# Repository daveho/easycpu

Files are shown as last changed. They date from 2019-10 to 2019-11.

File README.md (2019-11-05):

# Easy 8 bit CPU

This is a design for an 8 bit CPU built from 74HC logic chips.

It is totally just for fun.  I may try to complete it at some point but for now it's only at the idea stage.

The [design](design) directory has a block diagram that is probably the most useful document for explaining how the CPU is intended to work.

One potentially useful component that is (probably) ready for use is a passive backplane design, which is in the [backplane2](backplane2) directory.

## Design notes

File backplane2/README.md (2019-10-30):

# Backplane

This is a passive backplane for projects (such as 8 bit micros and
TTL CPUs) where there are lots of parallel bus connections that
would be a pain to wire on breadboards.

The idea is that the project can be built incrementally, with
circuit modules prototyped on a small number of breadboards, and
then permanantly constructed and attached to the backplane.

The eventual finished system then uses the backplane to allow
the various circuit modules to communicate.

Kicad template from <https://github.com/Squantor/templates_kicad/tree/master/OSH_Park_2_layer>

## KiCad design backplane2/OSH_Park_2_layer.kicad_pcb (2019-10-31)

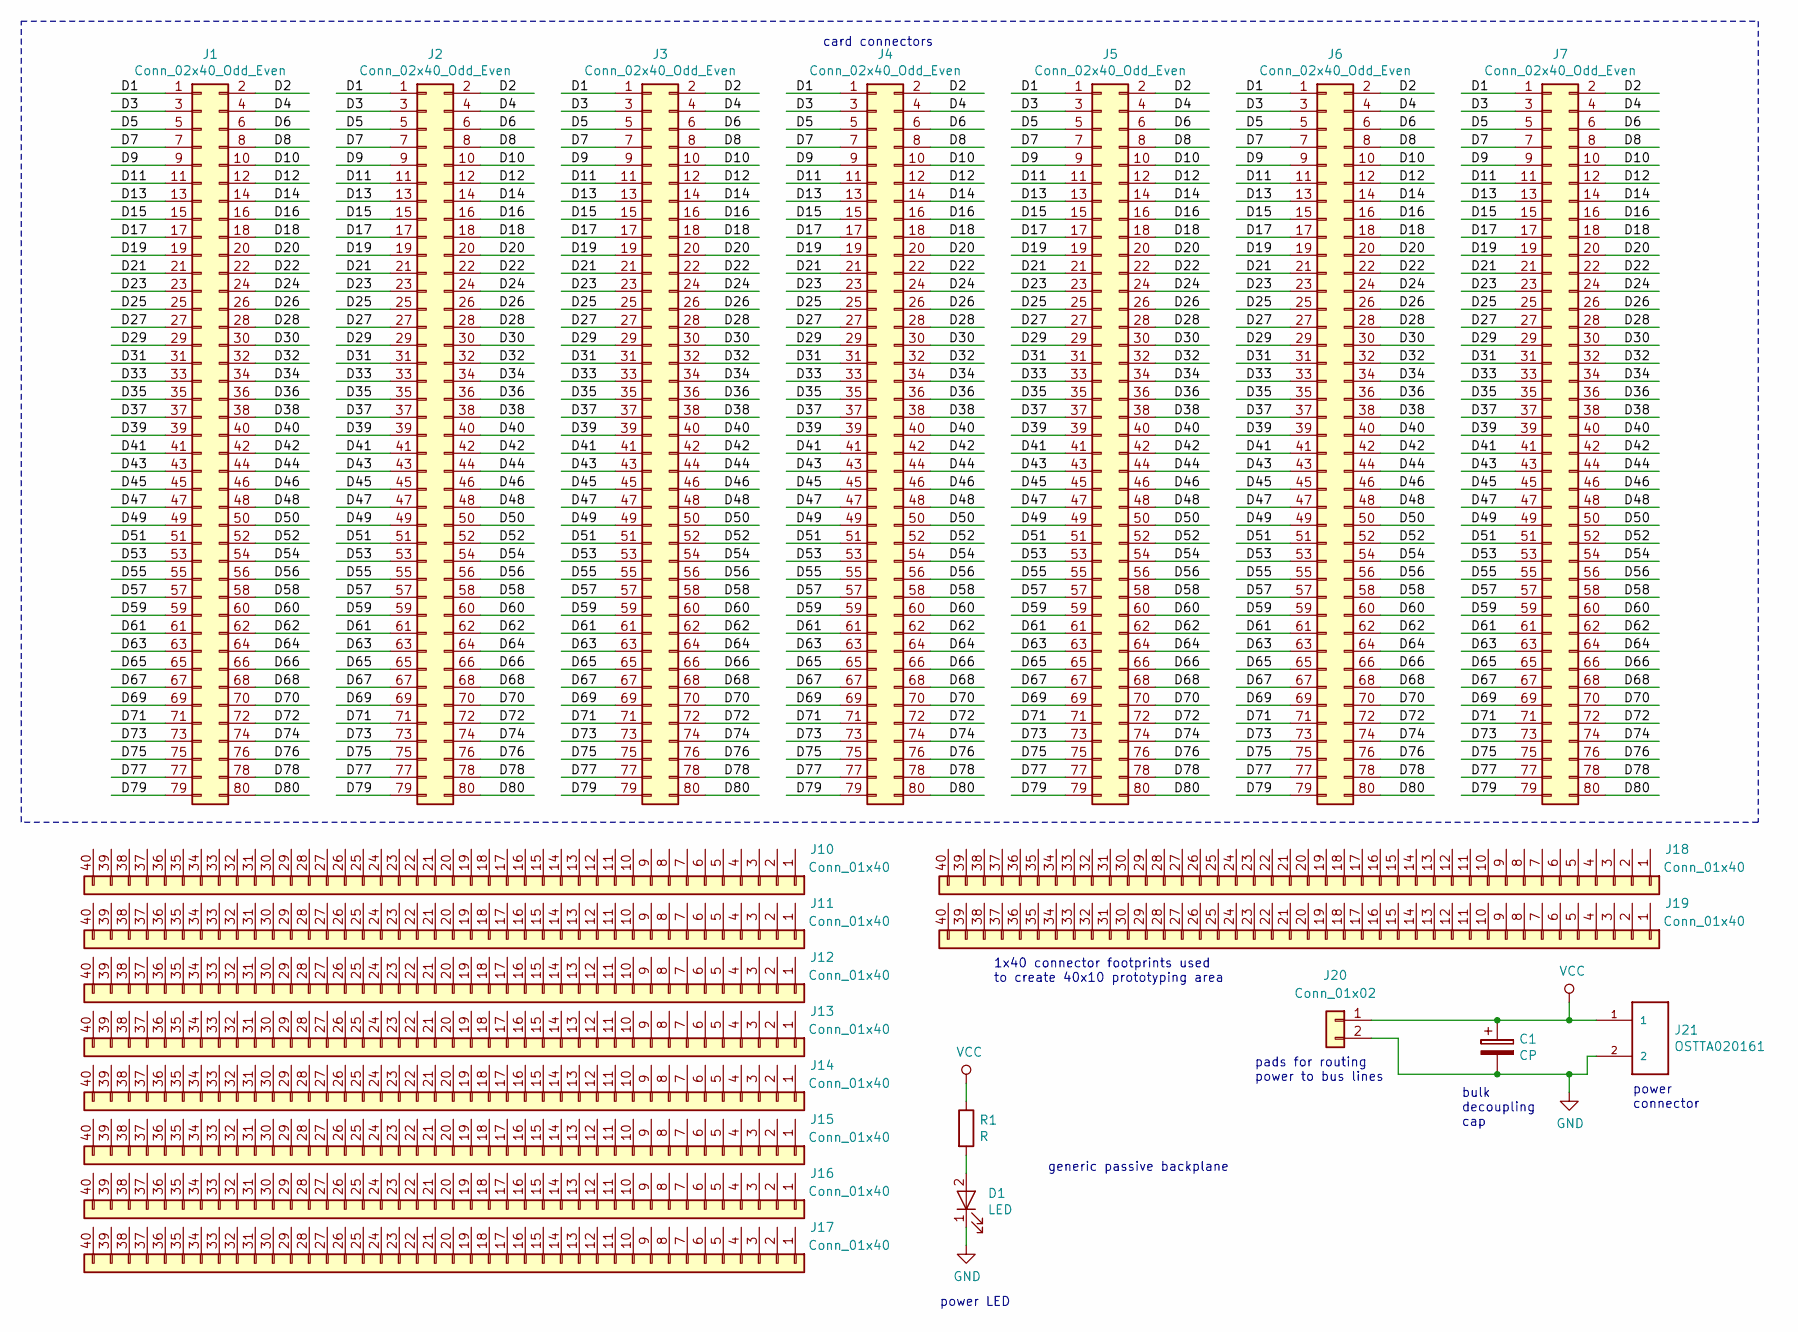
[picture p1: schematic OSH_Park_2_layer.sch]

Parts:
C1: CP; CP_Radial_D8.0mm_P2.50mm
D1: LED; LED_D5.0mm
J1, J2, J3, J4, J5, J6, J7: Conn_02x40_Odd_Even; PinHeader_2x40_P2.54mm_Vertical
J10, J11, J12, J13, J14, J15, J16, J17, J18, J19: Conn_01x40; PinHeader_1x40_P2.54mm_Vertical
J20: Conn_01x02; PinHeader_1x02_P2.54mm_Vertical
J21: OSTTA020161; OST_OSTTA020161
R1: R; R_Axial_DIN0204_L3.6mm_D1.6mm_P7.62mm_Horizontal

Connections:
/D1: J1.1, J2.1, J3.1, J4.1, J5.1, J6.1, J7.1
/D2: J1.2, J2.2, J3.2, J4.2, J5.2, J6.2, J7.2
/D3: J1.3, J2.3, J3.3, J4.3, J5.3, J6.3, J7.3
/D4: J1.4, J2.4, J3.4, J4.4, J5.4, J6.4, J7.4
/D5: J1.5, J2.5, J3.5, J4.5, J5.5, J6.5, J7.5
/D6: J1.6, J2.6, J3.6, J4.6, J5.6, J6.6, J7.6
/D7: J1.7, J2.7, J3.7, J4.7, J5.7, J6.7, J7.7
/D8: J1.8, J2.8, J3.8, J4.8, J5.8, J6.8, J7.8
/D9: J1.9, J2.9, J3.9, J4.9, J5.9, J6.9, J7.9
/D10: J1.10, J2.10, J3.10, J4.10, J5.10, J6.10, J7.10
/D11: J1.11, J2.11, J3.11, J4.11, J5.11, J6.11, J7.11
/D12: J1.12, J2.12, J3.12, J4.12, J5.12, J6.12, J7.12
/D13: J1.13, J2.13, J3.13, J4.13, J5.13, J6.13, J7.13
/D14: J1.14, J2.14, J3.14, J4.14, J5.14, J6.14, J7.14
/D15: J1.15, J2.15, J3.15, J4.15, J5.15, J6.15, J7.15
/D16: J1.16, J2.16, J3.16, J4.16, J5.16, J6.16, J7.16
/D17: J1.17, J2.17, J3.17, J4.17, J5.17, J6.17, J7.17
/D18: J1.18, J2.18, J3.18, J4.18, J5.18, J6.18, J7.18
/D19: J1.19, J2.19, J3.19, J4.19, J5.19, J6.19, J7.19
/D20: J1.20, J2.20, J3.20, J4.20, J5.20, J6.20, J7.20
/D21: J1.21, J2.21, J3.21, J4.21, J5.21, J6.21, J7.21
/D22: J1.22, J2.22, J3.22, J4.22, J5.22, J6.22, J7.22
/D23: J1.23, J2.23, J3.23, J4.23, J5.23, J6.23, J7.23
/D24: J1.24, J2.24, J3.24, J4.24, J5.24, J6.24, J7.24
/D25: J1.25, J2.25, J3.25, J4.25, J5.25, J6.25, J7.25
/D26: J1.26, J2.26, J3.26, J4.26, J5.26, J6.26, J7.26
/D27: J1.27, J2.27, J3.27, J4.27, J5.27, J6.27, J7.27
/D28: J1.28, J2.28, J3.28, J4.28, J5.28, J6.28, J7.28
/D29: J1.29, J2.29, J3.29, J4.29, J5.29, J6.29, J7.29
/D30: J1.30, J2.30, J3.30, J4.30, J5.30, J6.30, J7.30
/D31: J1.31, J2.31, J3.31, J4.31, J5.31, J6.31, J7.31
/D32: J1.32, J2.32, J3.32, J4.32, J5.32, J6.32, J7.32
/D33: J1.33, J2.33, J3.33, J4.33, J5.33, J6.33, J7.33
/D34: J1.34, J2.34, J3.34, J4.34, J5.34, J6.34, J7.34
/D35: J1.35, J2.35, J3.35, J4.35, J5.35, J6.35, J7.35
/D36: J1.36, J2.36, J3.36, J4.36, J5.36, J6.36, J7.36
/D37: J1.37, J2.37, J3.37, J4.37, J5.37, J6.37, J7.37
/D38: J1.38, J2.38, J3.38, J4.38, J5.38, J6.38, J7.38
/D39: J1.39, J2.39, J3.39, J4.39, J5.39, J6.39, J7.39
/D40: J1.40, J2.40, J3.40, J4.40, J5.40, J6.40, J7.40
/D41: J1.41, J2.41, J3.41, J4.41, J5.41, J6.41, J7.41
/D42: J1.42, J2.42, J3.42, J4.42, J5.42, J6.42, J7.42
/D43: J1.43, J2.43, J3.43, J4.43, J5.43, J6.43, J7.43
/D44: J1.44, J2.44, J3.44, J4.44, J5.44, J6.44, J7.44
/D45: J1.45, J2.45, J3.45, J4.45, J5.45, J6.45, J7.45
/D46: J1.46, J2.46, J3.46, J4.46, J5.46, J6.46, J7.46
/D47: J1.47, J2.47, J3.47, J4.47, J5.47, J6.47, J7.47
/D48: J1.48, J2.48, J3.48, J4.48, J5.48, J6.48, J7.48
/D49: J1.49, J2.49, J3.49, J4.49, J5.49, J6.49, J7.49
/D50: J1.50, J2.50, J3.50, J4.50, J5.50, J6.50, J7.50
/D51: J1.51, J2.51, J3.51, J4.51, J5.51, J6.51, J7.51
/D52: J1.52, J2.52, J3.52, J4.52, J5.52, J6.52, J7.52
/D53: J1.53, J2.53, J3.53, J4.53, J5.53, J6.53, J7.53
/D54: J1.54, J2.54, J3.54, J4.54, J5.54, J6.54, J7.54
/D55: J1.55, J2.55, J3.55, J4.55, J5.55, J6.55, J7.55
/D56: J1.56, J2.56, J3.56, J4.56, J5.56, J6.56, J7.56
/D57: J1.57, J2.57, J3.57, J4.57, J5.57, J6.57, J7.57
/D58: J1.58, J2.58, J3.58, J4.58, J5.58, J6.58, J7.58
/D59: J1.59, J2.59, J3.59, J4.59, J5.59, J6.59, J7.59
/D60: J1.60, J2.60, J3.60, J4.60, J5.60, J6.60, J7.60
/D61: J1.61, J2.61, J3.61, J4.61, J5.61, J6.61, J7.61
/D62: J1.62, J2.62, J3.62, J4.62, J5.62, J6.62, J7.62
/D63: J1.63, J2.63, J3.63, J4.63, J5.63, J6.63, J7.63
/D64: J1.64, J2.64, J3.64, J4.64, J5.64, J6.64, J7.64
/D65: J1.65, J2.65, J3.65, J4.65, J5.65, J6.65, J7.65
/D66: J1.66, J2.66, J3.66, J4.66, J5.66, J6.66, J7.66
/D67: J1.67, J2.67, J3.67, J4.67, J5.67, J6.67, J7.67
/D68: J1.68, J2.68, J3.68, J4.68, J5.68, J6.68, J7.68
/D69: J1.69, J2.69, J3.69, J4.69, J5.69, J6.69, J7.69
/D70: J1.70, J2.70, J3.70, J4.70, J5.70, J6.70, J7.70
/D71: J1.71, J2.71, J3.71, J4.71, J5.71, J6.71, J7.71
/D72: J1.72, J2.72, J3.72, J4.72, J5.72, J6.72, J7.72
/D73: J1.73, J2.73, J3.73, J4.73, J5.73, J6.73, J7.73
/D74: J1.74, J2.74, J3.74, J4.74, J5.74, J6.74, J7.74
/D75: J1.75, J2.75, J3.75, J4.75, J5.75, J6.75, J7.75
/D76: J1.76, J2.76, J3.76, J4.76, J5.76, J6.76, J7.76
/D77: J1.77, J2.77, J3.77, J4.77, J5.77, J6.77, J7.77
/D78: J1.78, J2.78, J3.78, J4.78, J5.78, J6.78, J7.78
/D79: J1.79, J2.79, J3.79, J4.79, J5.79, J6.79, J7.79
/D80: J1.80, J2.80, J3.80, J4.80, J5.80, J6.80, J7.80
GND: C1.2, D1.1 (K), J20.2, J21.2
unnamed: D1.2 (A), R1.2
VCC: C1.1, J20.1, J21.1, R1.1

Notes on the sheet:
card connectors
1x40 connector footprints used to create 40x10 prototyping area
power connector
generic passive backplane
pads for routing power to bus lines
bulk decoupling cap
power LED

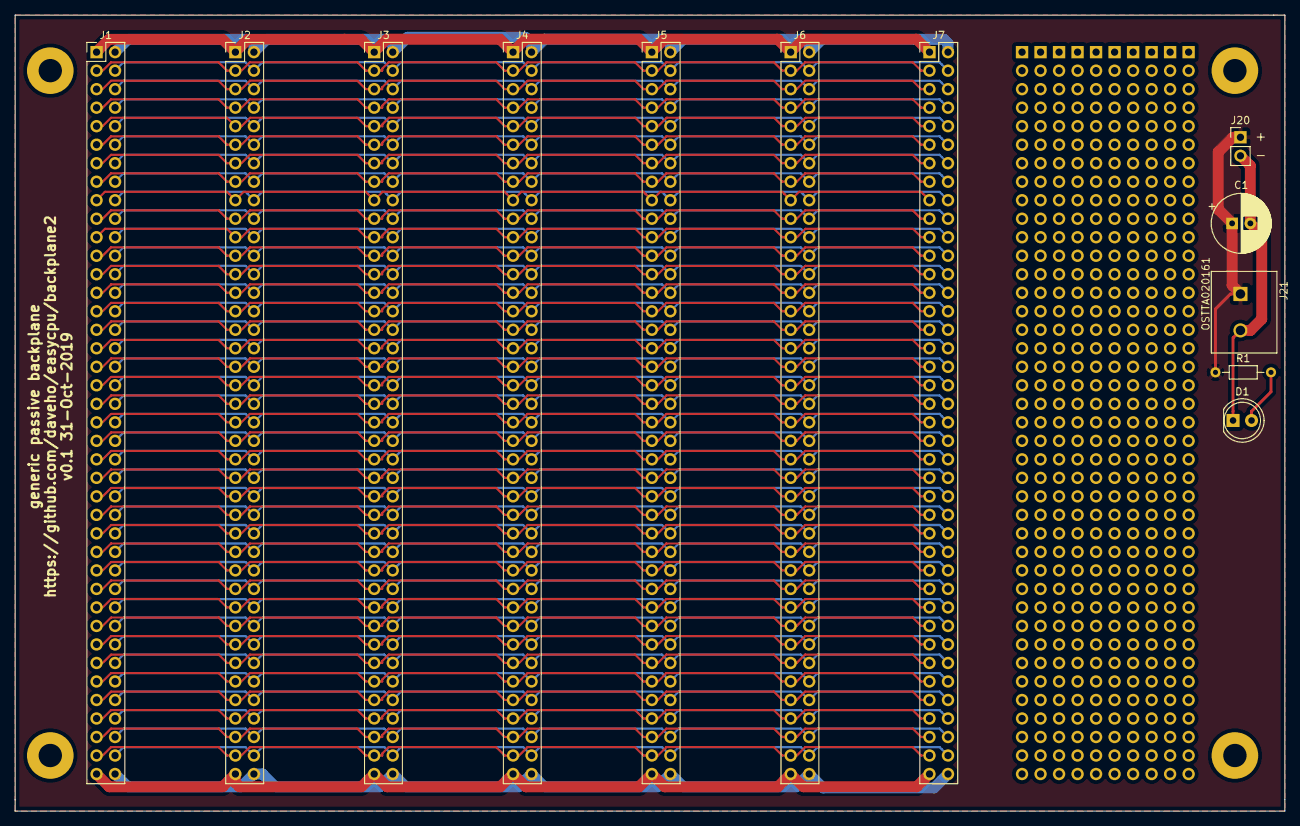
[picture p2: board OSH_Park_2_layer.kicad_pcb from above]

Board: 2 copper layers, 174.2 x 109.2 mm, 23 parts (0 on the bottom side), 83 nets.

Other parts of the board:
N2: 20190704; Label_version

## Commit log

2019-10-12 started working on control unit
    [addressGen.sch, control.sch, easycpu.sch]
2019-10-12 annotate control schematic, add other 74HC74 units
    [control.sch, easycpu.sch]
2019-10-12 added reset unit, some cleanups of control unit
    [addressGen.sch, control.sch, easycpu.sch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]
2019-10-12 control cleanup, generate proper clock for IR load
    [control.sch]
2019-10-14 start working on ucode and ucode assembler
    I'm focusing on the control unit at the beginning
    since it will be running the show.
2019-10-14 some cleanups/schematic improvements
    [addressGen.sch, control.sch, easycpu.sch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]
2019-10-18 create combined clock/reset circuit
    Clock circuit will be removed from control schematic.
    [addressGen.sch, clockReset.sch, control.sch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]
2019-10-18 generation of -R/-W signals for mem transactions
    [control.sch]
2019-10-19 minor tweaks, added sheet pins on main schematic?
    [addressGen.sch, clockReset.sch, control.sch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]
2019-10-19 minor gate swap
    [addressGen.sch, clockReset.sch, control.sch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]
2019-10-19 some schematic cleanups and descriptive text added
    [clockReset.sch, control.sch]
2019-10-19 more signals, actually assemble instructions
2019-10-19 use '273 registers for ucode, initial PC design
    The microcode registers need to be reset to a known
    state on startup. The 74HCT273 is appropriate for this.
    One consequence is that all microcode signals must be
    designed such that a 0 is the correct output for
    coming out of reset: the main thing that needs to
    happen is putting an initial value into the program
    counter. I'm assuming that a '541 buffer will
    put an appropriate byte value (maybe 0xC0) on the
    D bus on reset, and the PC can load this in both
    bytes (so, effective initial PC of 0xC0C0).
    Created an initial design for the program counter.
    Used 74HC191 synchronous counters, with a 74HC10
    triple 3-input NAND to enable counting for each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
    [addressGen.sch, clockReset.sch, control.sch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]
2019-10-26 program counter is now 2x 74HCT574
    Increment is done using the address generation unit,
    and the output of address generation can be optionally
    sent back to the address registers (such as PC)
    via buffers.
    This hugely simplifies the program counter implementation,
    and also makes it easy to provide additional address
    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
    [addressGen.sch, clockReset.sch, control.sch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]
2019-10-26 added submodule with all address regs (PC, SP, X)
    [addrReg.sch, addressGen.sch, clockReset.sch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]
2019-10-26 address registers have only one load input
    Both bytes of the address will always be loaded
    at the same time.
    Also did a few cleanups of the addrReg schematic.
    [addrReg.sch, addressGen.sch, clockReset.sch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]
2019-10-26 added schematic for general purpose registers
    [addrReg.sch, addressGen.sch, clockReset.sch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]
2019-10-26 simplified GP regs slightly
    An output enable signal for the operand registers
    (R0-R3) is not necessary. The address 0-3 selects
    which one generates output.
    [easycpu.sch, gpReg.sch]
2019-10-27 added ALU module
    [addrReg.sch, addressGen.sch, alu.sch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]
2019-10-27 possible design for passive backplane
    [backplane.kicad_pcb, backplane.sch]
2019-10-27 added ALo/AHi output buffers to addrGen unit
    [addrReg.sch, addressGen.sch, alu.sch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]
2019-10-27 -1 constant outputs don't require hw or control
    They can be generated implicitly with the bus pull-up
    resistors.
2019-10-27 generation of 0 and 1 constant offsets in addrGen
    Also added pullup resistors to the offset bus to ensure
    inputs are valid and also to implicitly generate the
    -1 constant offset.
    [addressGen.sch, easycpu.sch, gpReg.sch]
2019-10-30 backplane project from OSH park template
    [OSH_Park_2_layer.kicad_pcb, OSH_Park_2_layer.sch]
2019-10-30 added power connector and power LED
    [OSH_Park_2_layer.sch]
2019-10-30 selected component footprints
    [OSH_Park_2_layer.sch]
2019-10-30 working on board design
    [OSH_Park_2_layer.kicad_pcb, OSH_Park_2_layer.sch]
2019-10-31 routed half of the backplane connections
    [OSH_Park_2_layer.kicad_pcb]
2019-10-31 completely routed?
    [OSH_Park_2_layer.kicad_pcb]
2019-10-31 added 4 power distribution traces
    also fixed a couple of unconnected nets
    [OSH_Park_2_layer.kicad_pcb]
2019-10-31 minor tweak to power LED placement
    [OSH_Park_2_layer.kicad_pcb]
2019-10-31 updated date (ready to fab now?)
    [OSH_Park_2_layer.kicad_pcb]
2019-10-31 exported gerber files
    [OSH_Park_2_layer-B_Cu.gbl, OSH_Park_2_layer-B_Mask.gbs, OSH_Park_2_layer-B_SilkS.gbo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]
